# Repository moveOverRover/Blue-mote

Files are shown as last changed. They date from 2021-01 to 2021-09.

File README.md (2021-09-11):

# Blue-mote
This contains the stl files, code, and media for my Bluetooth remote project. But has more recently been taken over by my adventures of creating an android application to replace the remote (please do have a look at that, its pretty cool).
  
I started this project well over a year ago and it taught me a lot, certainly more than I want to write in this read me. Visiting the code of each project version will provide a deeper dive into the challenges and victories I found.

A lot of this repo is my first creating a controller, and then spending a year trying to figure out why half the time the messages I receive are not the ones I sent even though Bluetooth has a pretty bullet proof protocol.

I dig into parity, checksums, message frames, and end up making something like my own protocol even though I have never run it on hardware that isn’t already running its own error correction (although I might buy some cheep transmitters/receivers that have nothing else going on and give it a shot later).

In the end I believe the problem was my placing long wires in noisy environments between the simpler UART interfaces that was giving me the problem (1 parity bit might not be enough with a 2kw motor next to it). It was either that or a misunderstanding of how Arduino’s/HC-05 input buffers work because sometimes they would give me unreasonable values.
<p float="left">
  Screenshot_20210810-084741_BluetoothShenanegans2
  Screenshot_20210810-084846_BluetoothShenanegans3
</p>

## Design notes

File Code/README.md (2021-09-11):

# All arduino code lives here
Note: As of 2021-09-09 all of this code is legacy

remoteRover and miniJeep are two robots I built for testing the controller on. I wanted to upgrade the smaller remoteRover but I never got to it and its sitting disassembled for the time being. A lot more testing was done on miniJeep so the code there is more interesting. remoteControl is obviously just the physical remote.

A note about minijeep, it was a power wheels car, the kind of electric car parents buy for their kids. Someone was throwing it out if you can believe it, all it needed was a new battery. After that I made it remote control but that’s a story for another read me.

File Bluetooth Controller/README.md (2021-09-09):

# Stl files for 3d printing the controller

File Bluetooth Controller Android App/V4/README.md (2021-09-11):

# This version Is a game changer!

All the problems I have been having with unreliable communications have been solved with the version.
The way I did this is by implementing my most complicated message frame yet, I call it Butter-Scotch.
And this is what it looks like:

Butter Scotch message frame:

 each capital letter is a nibble, lowercase is a bit, * is multiplication
 
 by Bytes:                            AA AA Bxxxc DD 1-250*EE FF FF
 
                AA                AA     B             xxxc              DD           1-250* EE        FF FF
                
   message length^ | message length^ | ID^ | Received bit?^ | message type^ | message contents^ | check sum^
   
 Overview:
 
 I was inspired after learning about the CAN bus protocol and I implemented a few key parts of it. When the device receives data to its input buffer it will wait until
 at least 2 bytes have been received. then the message length can be decoded by reading the first 2 bytes as binary numbers and making sure they are the same (if they are different, we, have corruption and we can decide what to do with that). Now that we know the message length we can take in the right number of bytes and check that the data is good using the
 checksum at the end of the data. The ID is useful if multiple devices are hooked up to a single Bluetooth module on the Arduino side, this allows the Arduino to determine if the
 message is intended for it. The ID byte also contains a 3 don’t care bits and a acknowledge bit that so the device can determine if the previous message was received and decide what to do.
 The message type byte is a binary number that is a code in a shared array or HashMap that contains the instructions on what to do with the message content bytes.
 finally the checksum ensures good data.
 
 Message contents:
 
 The message contents are a series of binary numbers that can be interpreted in different ways based on the message type's value.
 For example: if the message type is 1 then interpret the binary contents as 3 integers 1 byte long each. If you can map whatever data you want to send to a single byte then
 the frame becomes very convenient. I have functions and classes that do this but what if you want to send something more complicated than a short short int? Well, I have functions
 and classes for that too. A float for example would be sent with a different message type to indicate how it should be read. Floats are not stored in the message traditionally
 with a sign bit, an exponent and a fraction. Instead, I chose to separate the float into 2 parts: the first is a variable length integer that represents the numbers before the decimal
 and a 2-byte integer representing the numbers after the decimal. Once received I just splice them back together. I choose to do it this way because it was easier for me since I already had
 all the functions to do this. The pit falls of doing it this way are you would need a whole byte to show its a negative number (but I’ve never need to send a negative float yet) and its not
 space efficient (which I don’t care about since the message can be 250 bytes long). finally, strings are just sent as ascii with an appropriate type. There are better ways to do this
 but this is my way, and it works!
 
 App updates:
 
 This version actually receives data from the Arduino and can display it with its new custom progress bar. 1 for motor temperature, 1 for battery voltage, and 1 for throttle input (on the smartphone side). Along with that the text view now display stats about the messaging between the Arduino and the phone for debugging and connection health. I also have added a new menu to change the leds that are now on my electric long board. You can set them to be any color with sliders, and also choose from a mix of colors or action mode which is green when accelerating, blue when costing and red when braking. But most impressively this communication finally has no errors. I can detect errors on both the Arduino side and the app side because of the received bit and checksum in the message frame. However, since I can now confidently read the length of the message without using the input buffers 'Available()' function I have not had a single error. It is finally working how it should have from the first place. I don’t know why the input buffer on both the app side and the Arduino side is falsely reporting the size of the received data but not paying any attention seems to have fixed that problem. All this time and I still don’t know why, but now I know how and that feels great.

 <p float="left">
  Screenshot_20210810-084741_BluetoothShenanegans2
  Screenshot_20210810-084846_BluetoothShenanegans3
  Screenshot_20210810-084846_BluetoothShenanegans3
</p>

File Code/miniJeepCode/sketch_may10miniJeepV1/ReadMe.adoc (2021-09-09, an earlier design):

:Author: moveoverrover
:Email: {AuthorEmail}
:Date: 10/05/2021
:Revision: version#
:License: Public Domain

= Project: {Project}

Describe your project

== Step 1: Installation
Please describe the steps to install this project.

For example:

1. Open this file
2. Edit as you like
3. Release to the World!

== Step 2: Assemble the circuit

Assemble the circuit following the diagram layout.png attached to the sketch

== Step 3: Load the code

Upload the code contained in this sketch on to your board

=== Folder structure

....
 sketch123                => Arduino sketch folder
  ├── sketch123.ino       => main Arduino file
  ├── schematics.png      => (optional) an image of the required schematics
  ├── layout.png          => (optional) an image of the layout
  └── ReadMe.adoc         => this file
....

=== License
This project is released under a {License} License.

=== Contributing
To contribute to this project please contact moveoverrover https://id.arduino.cc/moveoverrover

=== BOM
Add the bill of the materials you need for this project.

|===
| ID | Part name      | Part number | Quantity
| R1 | 10k Resistor   | 1234-abcd   | 10
| L1 | Red LED        | 2345-asdf   | 5
| A1 | Arduino Zero   | ABX00066    | 1
|===

=== Help
This document is written in the _AsciiDoc_ format, a markup language to describe documents.
If you need help you can search the http://www.methods.co.nz/asciidoc[AsciiDoc homepage]
or consult the http://powerman.name/doc/asciidoc[AsciiDoc cheatsheet]

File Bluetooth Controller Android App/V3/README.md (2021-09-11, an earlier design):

# V3

This version adds 2 analog inputs because of the digital joystick.

This implementation of the joystick was not perfect.
I had trouble offsetting the sprite of the joystick from the position of the finger because the coordinates of the sprite start at the top left corner of the sprite not the middle.
Some strange looking offsets had to made because of this and it interfered with the way I would map the position of the joystick to its actual value.

Other than that, pretty similar to V2.
I did clean up the UI and switched it to a relative layout. I Also implement some new features like toasts and an option to set the origin of the joystick anywhere on the screen.
Because of these changes this version of the app should* fit on any phone screen unlike the last one.
We are still using the miniJeep3 message frame as well.

<p float="left">
  Screenshot_20210810-084741_BluetoothShenanegans2
  Screenshot_20210810-084846_BluetoothShenanegans3
</p>

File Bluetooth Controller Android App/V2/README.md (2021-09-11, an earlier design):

# V2
Very first working version of the Bluetooth app. Used digital button inputs to emulate the message frame that miniJeep3 was receiving (check out moveOverRover/Blue-mote/code for more details).UI was not great, and everything was on a relative layout But it did work however and it taught me a lot. The next version improved on a lot of the short comings of this such as analog inputs and better UI.
<p float="left">
  Screenshot_20210810-084741_BluetoothShenanegans2
  Screenshot_20210810-084846_BluetoothShenanegans3
</p>

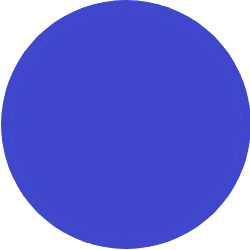
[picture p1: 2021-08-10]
Bluetooth Controller Android App/V4/pad.png

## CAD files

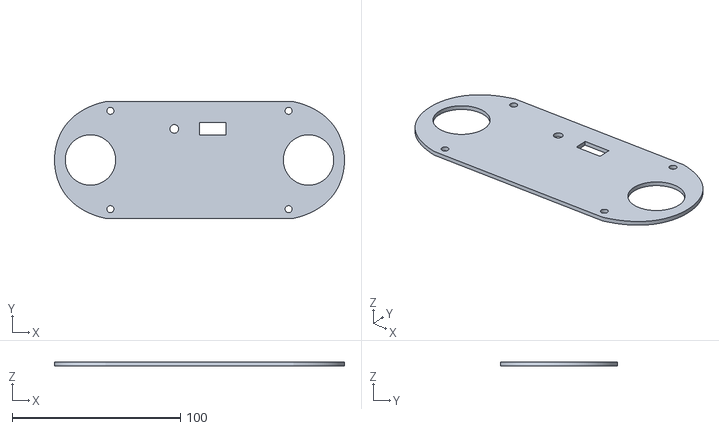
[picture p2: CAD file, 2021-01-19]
Bluetooth Controller/Blue-mote cover v3.stl
172.5 x 69.5 x 2.25

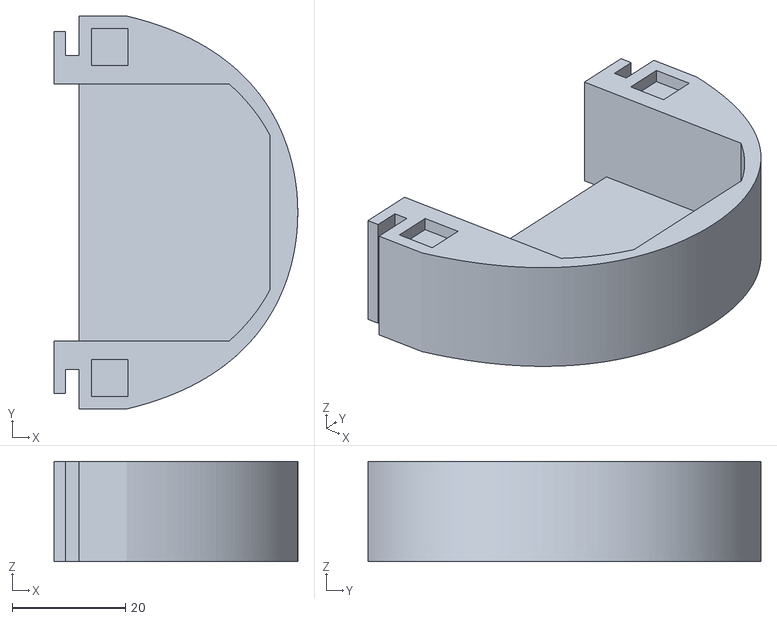
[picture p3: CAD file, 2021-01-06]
Bluetooth Controller/New Joystick compartment A v1.stl
43.1 x 69.5 x 17.8

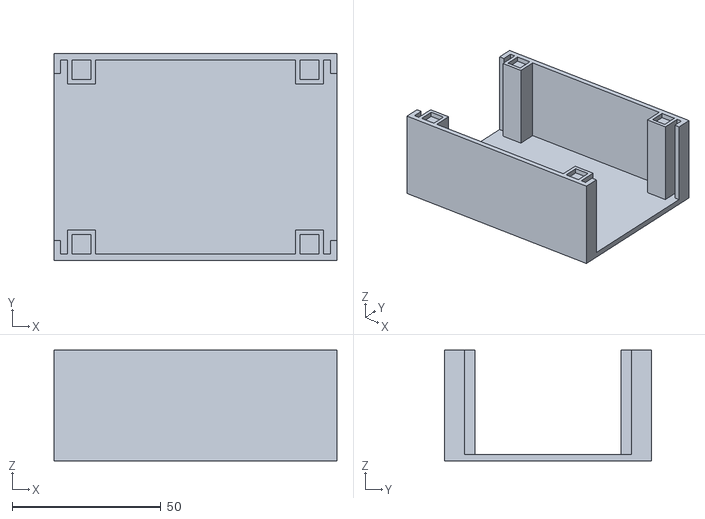
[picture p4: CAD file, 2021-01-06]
Bluetooth Controller/Bluetooth Remote Core A v4.stl
95.0 x 69.5 x 37.2

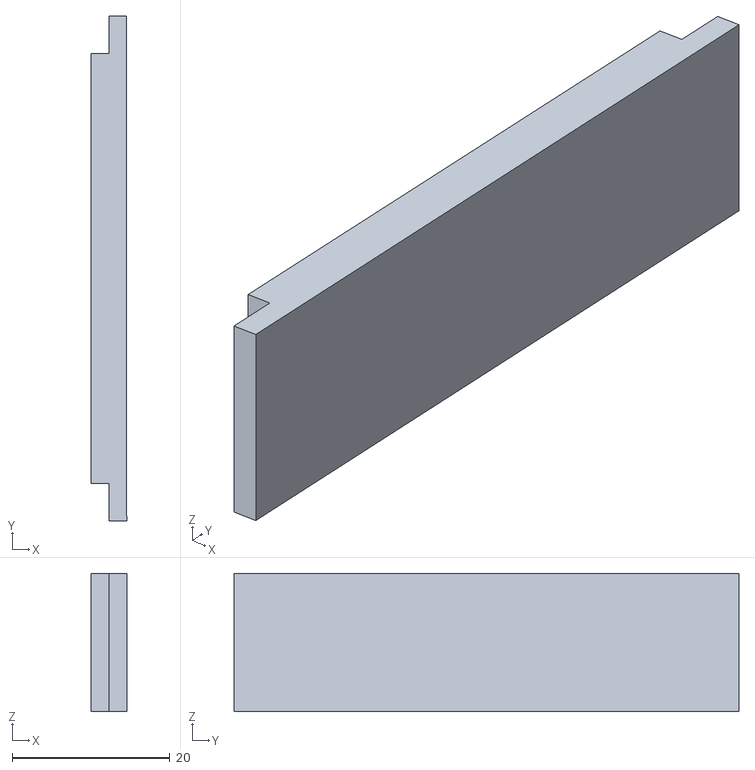
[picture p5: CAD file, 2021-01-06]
Bluetooth Controller/Bluetooth cover small v1.stl
4.50 x 64.0 x 17.5

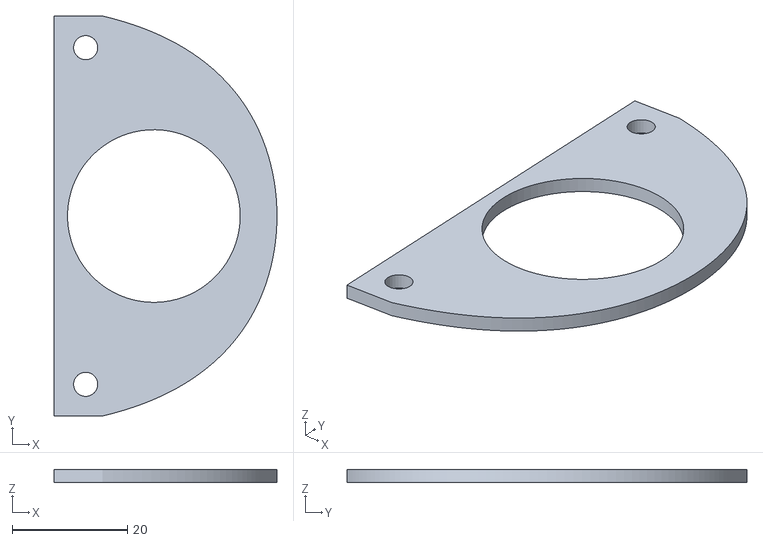
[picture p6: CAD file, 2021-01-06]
Bluetooth Controller/Joystick cover v2.stl
38.7 x 69.5 x 2.25

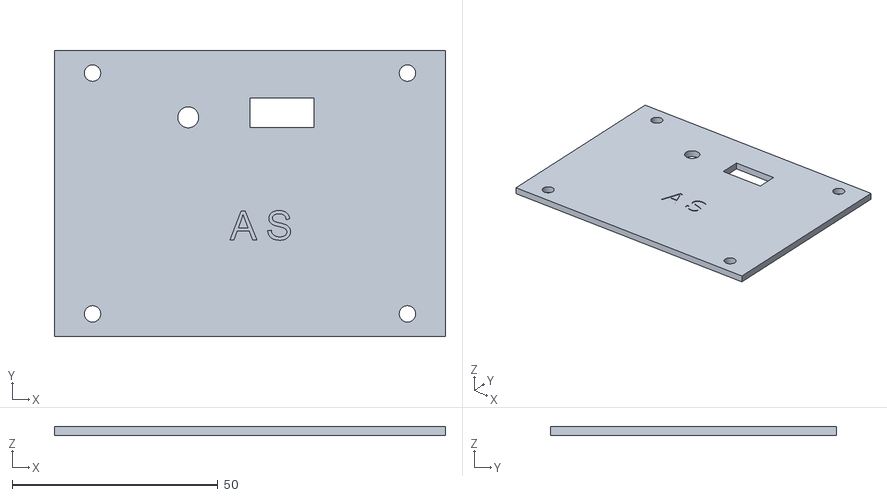
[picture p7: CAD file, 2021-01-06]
Bluetooth Controller/B Bluetooth Core v3.stl
95.0 x 69.5 x 2.25

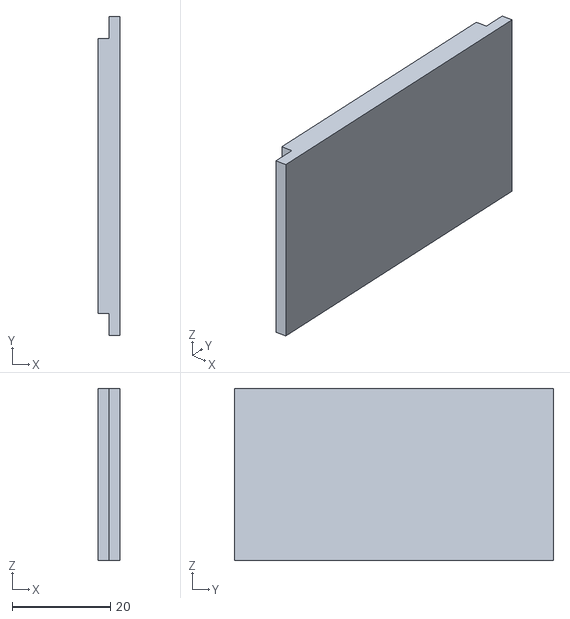
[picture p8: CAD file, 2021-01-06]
Bluetooth Controller/cover Bluetooth v2.stl
4.45 x 65.0 x 35.0

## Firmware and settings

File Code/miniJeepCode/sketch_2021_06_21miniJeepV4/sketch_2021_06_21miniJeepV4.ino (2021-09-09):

/* author: Alex Semenov
  Forth resonable working version
  Very simmialr to the third version but now we attempt to talk back to the controller with some data. Never was used after I made this I quickly tranitioned
  to using Butter Scotch after this was complete.
*/
#define INC_MSG 7 // size of the incomming message
#define OUT_MSG 5 // size of the outgoing message

#define D1 3 // drive pin one
#define D2 4 // drive pin two
#define D3 5 // drive pin three
#define T1 6 // turning pin one
#define T2 7 // turning pin two
#define T3 8 // turning pin three
#define HORN 11 
#define LIGHTS 10
#define MUSIC 12
#define X_UPPER 175 // upper limit of dead zone x joystick 
#define X_LOWER 80 // lower limit of dead zone x joystick
#define Y_UPPER 175 // upper limit of dead zone y joystick 
#define Y_LOWER 75 // lower limit of dead zone y joystick
#define SAFTY_PIN 2 // pint that reads the state of the bluetooth modual

int x = 130; // current x position
int y = 130; // current y position
int z = 0; // state of digital functions
char horn = 'b'; 
char lights = 'd';
char music = 'f';
volatile int p = 0; // if information has been resently recived p=0
char cmd[INC_MSG]; // incoming message
char srt; // buffer var
char ret[OUT_MSG];
volatile int j; // amount of serial events

int power(int a, int b){ // a = base, b = exponent
  if(b==0){
    return 1;
  }
  int og = a;
  for(int q=0; q<b-1; q++){
    a = a*og;
  }
  return a;
}

unsigned long int bytes2Int(char *bytes, int leng, int offset){ // makes a series of bytes into a binary number which is returned as an integer
 byte mask;
 unsigned long int sum = 0;
  
  for (int i=leng; i>offset; i--){ // repetes untill every byte has been prosessed start at last byte
    mask = 0x01;
    for (int k=0; k<8; k++){ // start at first bit
      if(bytes[i-1] & mask){ // if bit is 1
       sum += power(2,k+(8*(leng-i))); // add bit
      }
      mask <<= 1; // bit shift mask to the left
    }
  }
  return sum;
}

void int2Bytes(int num, char* bytes, int leng, int offset){ // writes a binary number from an int
  for (int i=offset; i<leng+offset; i++){ //sets all bits in message to 0
    bytes[i] = 0x00;
  }
  
  if (num%2 != 0){ // if num is odd then we know the first bit is a 1
    bytes[leng+offset-1] = bytes[leng+offset-1] | 0x01;
  }
  
  int shift, pos;
  byte mask;
  int tempNum = num;
  
  while ((shift=int2Bit(tempNum)) != 0){ // while there is bits left to add
    tempNum = tempNum - power(2,shift); // removes previous bit
    mask = 0x01; // resets the mask
    mask <<= shift%8; // moves the mask to the current bit
    pos = bytePos(leng, shift); //finds the current byte
    bytes[pos+offset] = bytes[pos+offset] | mask; // adds the bit to the byte
  }
}

int int2Bit(int tempNum){ // determines bigest bit position of checksum
  int k =0;
  while((tempNum =tempNum/2) >= 1){
   k++; 
  }
  return k;
}

int bytePos(int leng, int shift){ // counts the byte we are on based on the shift
  int pos = 0;
  while (shift>7){
    shift -=8;
    pos++;
  }
  return leng-pos-1; // -1 because arrays start at 0
}

int cSum(char* bytes, int leng){ // calcualtes integer checksum
  int sum =0;
  for (int k=0; k<leng; k++){
    sum+=bytes2Int(&bytes[k],1,0);
  }
  return sum;
}

void actions () {
  // this is for steering
  if (x > X_UPPER){
    digitalWrite(T1,HIGH);
    digitalWrite(T2,LOW);
    digitalWrite(T3,HIGH); 
  } else if (x < X_LOWER){
    digitalWrite(T1,HIGH);
    digitalWrite(T2,HIGH);
    digitalWrite(T3,LOW);
  } else {
    digitalWrite(T1,LOW);
    digitalWrite(T2,LOW);
    digitalWrite(T3,LOW);
  }
  // this is for dirving
  if (y > Y_UPPER){
    digitalWrite(D3,HIGH);
    digitalWrite(D2,LOW);
    digitalWrite(D1,HIGH);
  } else if (y < Y_LOWER) {
    digitalWrite(D3,HIGH);
    digitalWrite(D2,HIGH);
    digitalWrite(D1,LOW);
  } else {
    digitalWrite(D3,LOW);
    digitalWrite(D2,LOW);
    digitalWrite(D1,LOW);
  }
  
  // this is for the features
  if (horn == 'a') {
    digitalWrite(HORN, HIGH);
  } else if (horn == 'b') {
    digitalWrite(HORN, LOW);
  }
  if (lights == 'c') {
    digitalWrite(LIGHTS, HIGH);
  } else if (lights == 'd'){
    digitalWrite(LIGHTS, LOW);
  }
  if (music == 'e') {
    digitalWrite(MUSIC, HIGH);
  } else if (music == 'f') {
    digitalWrite(MUSIC, LOW);
  }
}

void serialEvent(){
  p=0; // good connection
  j++; // counts a serial event
  TCNT1  = 0x00; // should reset timer
}

void zDoer(){
  if(z == 0){ // OFF
    horn = 'b';
    lights = 'd';
    music = 'f';
  } else if (z == 1){ // LIGHTS
    horn = 'b';
    lights = 'c';
    music = 'f';
  } else if (z == 2){ // LIGHTS and HORN
    horn = 'a';
    lights = 'c';
    music = 'f';
  } else if (z == 3){ //  LIGHTS and MUSIC
    horn = 'b';
    lights = 'c';
    music = 'e';
  } else if (z == 4){ // HORN
    horn = 'a';
    lights = 'd';
    music = 'f';
  } else if (z == 5){ // MUSIC
    horn = 'b';
    lights = 'd';
    music = 'e';
  }
}

char* takeIn(char *bytes){
  int i=0;
  int flag = 0;
  while((srt = Serial.read()) != -1){ // read entire message to memory
    delay(2); // could by shorter?
    if(i<INC_MSG){
      bytes[i++] = srt;
    }
  }
  if (i==INC_MSG){ // if too few or too many bytes are recived throw the message away
    return bytes;
  } else {
    return NULL;
  }
}

ISR(TIMER1_COMPA_vect){//timer1 interrupt 5Hz: if timer is ever aloud to complete we have a bad connection
  p = 1; // bad connection
}

void debuggin(){
  /*
  Serial.print("cmd: ");
    for(int i=0;i<INC_MSG;i++){
      Serial.write(cmd[i]);
    }
    Serial.write('\n');
  
    Serial.print("a_x: ");
    Serial.println(bytes2Int(&cmd[0],1));
    Serial.print("a_y: ");
    Serial.println(bytes2Int(&cmd[1],1));
    Serial.print("b_x: ");
    Serial.println(bytes2Int(&cmd[2],1));
    Serial.print("b_y: ");
    Serial.println(bytes2Int(&cmd[3],1));
    Serial.print("z: ");
    Serial.println(z);
    
    Serial.print(cSum(cmd,5));
    Serial.print(" = ");
    Serial.println(bytes2Int(cmd,7,5));
    */

    Serial.print("0: ");
    Serial.println(x);
    Serial.print("1: ");
    Serial.println(bytes2Int(&cmd[1],1,0));
    Serial.print("2: ");
    Serial.println(bytes2Int(&cmd[2],1,0));
    Serial.print("3: ");
    Serial.println(y);
    
}

void setup(){ // compare match register = [16,000,000Hz/(prescaler*desired interupt frequency)]-1
  for(int k=3; k<13; k++){ // set all pins but 2 to be output
    if (k!=6){ // pin 6 has an internal short on current board
       pinMode(k,OUTPUT);
    }
    //digitalWrite(k, LOW);
  }
  Serial.begin(38400);
  pinMode(SAFTY_PIN, INPUT);
  pinMode(13,OUTPUT);
  j=0; // Very important to make zero

  cli(); //stop interrupts
  //set timer1 to 10Hz
  TCCR1A = 0;// set entire TCCR1A register to 0
  TCCR1B = 0;// same for TCCR1B
  TCNT1  = 0;//initialize counter value to 0
  // set compare match register for 10hz increments
  //OCR1A = 1500;// = (16*10^6) / (10*1024) - 1 (must be <65536) ***VERY IMPORTANT*** -LIKES TO BE A NUMBER THAT ENDS IN AT LEAST ONE '0', I HAVE NO IDEA WHY JUST LEAVE IT BE!
  OCR1A = 3000; // double the pervious time becuase it runs better this way
  // turn on CTC mode
  TCCR1B |= (1 << WGM12);
  // Set CS12 and CS10 bits for 1024 prescaler
  TCCR1B |= (1 << CS12) | (1 << CS10);  
  // enable timer compare interrupt
  TIMSK1 |= (1 << OCIE1A);
  sei();//allow interrupts
}

void loop() {
  if(j>INC_MSG){ //once enough bytes have been recived
    j=0;  // reset the war clock
    if (takeIn(cmd) != NULL){ // take in the bytes
      if (cSum(cmd,5) == bytes2Int(cmd,7,5)){ // if the check sum checks out then we can change stuff
        x = bytes2Int(&cmd[0],1,0);
        y = bytes2Int(&cmd[3],1,0);
        z = bytes2Int(&cmd[4],1,0);

        int2Bytes(1,ret,1,0); // if data was good then send good data conformation
      } else {
        int2Bytes(0,ret,1,0); // if data was bad then send bad data conformation
      }
      debuggin();
    } else {
      int2Bytes(0,ret,1,0); // if data was bad then send bad data conformation
    }
    int2Bytes(2,ret,1,1); // message contents
    int2Bytes(3,ret,1,2); // message contents
    int2Bytes(cSum(ret,3), ret, 2, 3); // checksum
    //for(int i=0; i<OUT_MSG; i++){
      //Serial.write(ret[i]);
    //}
  }
  
 if (p == 0 && digitalRead(SAFTY_PIN) == LOW){ // good conection *** saftey pin set low for testing
   digitalWrite(13,HIGH);
   zDoer();
   actions();
 } else { // bad conection
   digitalWrite(13,LOW);
   x = 130;
   y = 130;
   horn = 'b';
   lights = 'd';
   music = 'f';
   actions();
 }
}

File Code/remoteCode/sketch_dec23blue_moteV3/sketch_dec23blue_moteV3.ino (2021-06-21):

/* author: Alex Semenov
  Third resonable working version of the blue-tooth remote.
  Sends 2 more analog inputs than hte previous version (It now is sending every imput it has)
  Sends data at a lower resolution 8bit instead of 10 but with much more freqent sends and more data per send
  Calculates a checksum and send it with the data for error checking
  Much faster than the previous version (remeber to reduce the delay later can prolly be about 40)
*/
#define X_A A3 //left Joystick x-axis
#define Y_A A1 //left Joystick y-axis
#define X_B A4 //right Joysitck x-axis
#define Y_B A2 //right Joystick y-axis
#define TOGGLE 2
#define BTN_A 3
#define BTN_B 4
#define R 5 
#define B 6
#define G 7
int x_a, y_a, x_b, y_b, toggle, btn_a, btn_b, z;
char cmd [7];
char btn_c[4];

int power(int a, int b){ // a = base, b = exponent
  if(b==0){
    return 1;
  }
  int og = a;
  for(int q=0; q<b-1; q++){
    a = a*og;
  }
  return a;
}

byte int2Byte(int x, boolean yesMap){ // helper function
  if (yesMap){
    x = map(x, 0, 1023, 0, 255); //must fit in one byte
  }
  return (byte)x;
}

void byteSum(int checkSum, char* msg){ // writes a 2 bit binary number to be used as the checksum
  msg[5] = 0x00;
  msg[6] = 0x00;
  
  if (checkSum < 256){ // if the check sum is small we only need one byte so we can write the other one to be 0
    msg[5] = 0x00;
    msg[6] = (char)int2Byte(checkSum,false);
    return;
  }
  
  if (checkSum%2 != 0){ // if checkSum is odd then we know the first bit is a 1
    cmd[6] = cmd[6] | 0x01;
  }
  
  int shift;
  byte mask;
  int tempSum = checkSum;
  
  while ((shift=int2Bit(tempSum)) != 0){ // I forgot how all of this works too
    //Serial.print(shift);
    //Serial.print(": ");
    //Serial.println(tempSum);
    tempSum = tempSum - power(2,shift);
    mask = 0x01;
    if (shift > 7){
      shift -=8;
      mask <<= shift;
      msg[5] = msg[5] | mask;
    } else {
      mask <<= shift;
      msg[6] = msg[6] | mask;
    }
  }
}

int int2Bit(int tempSum){ // determines bigest bit position of checksum *** helper function
  int k =0;
  while((tempSum =tempSum/2) >= 1){
   k++; 
  }
  return k;
}

unsigned long int getSum(char *msg, int leng){ // makes a serires of bytes into a binary number which is returned as an integer
 byte mask;
 unsigned long int sum = 0;
  
  for (int i=leng; i>0; i--){ // repetes untill every byte has been prosessed start at last byte
    //if (msg[i-1] == 0x00){
    //  return 0;
    //}
    mask = 0x01;
    for (int j=0; j<8; j++){ // start at first bit
      if(msg[i-1] & mask){ // if bit is 1
       sum += power(2,j+(8*(leng-i))); // add bit
      }
      mask <<= 1; // bit shift mask to the left
    }
  }
  return sum;
}

int cSum(char* msg, int leng){ // calcualtes integer checksum
  int sum =0;
  for (int k=0; k<leng; k++){
    sum+=getSum(&msg[k],1);
  }
  return sum;
}

void assemble(char* msg){ // makes the message
  int checkSum = 0;
  msg[0] = (char)int2Byte(x_a, true);
  msg[1] = (char)int2Byte(x_b, true);
  msg[2] = (char)int2Byte(y_a, true);
  msg[3] = (char)int2Byte(y_b, true);
  msg[4] = (char)int2Byte(z, false);
  byteSum(cSum(cmd, 5), cmd);
}

void zDoer(){ // inner btn has proprity over outer btn
  if (btn_c[0] == 'b' && btn_c[1] == 'd' && btn_c[3] == 'f'){ // nothing
    z=0;
  } else if (btn_c[0] == 'a' && btn_c[1] == 'd' && btn_c[2] == 'f'){ // toggle
    z=1;
  } else if (btn_c[0] == 'a' && btn_c[1] == 'c' && btn_c[2] == 'f'){ // toggle + inner
    z=2;
  } else if (btn_c[0] == 'a' && btn_c[1] == 'd' && btn_c[2] == 'e') { // toggel + outer
    z=3;
  } else if (btn_c[1] == 'c') { // inner
    z=4;
  } else if (btn_c[2] == 'e') { // outer
    z=5;
  }
}

void btns(){
  if (toggle == 1) {
    digitalWrite(R, HIGH);
    digitalWrite(B, LOW);
    digitalWrite(G, LOW);
    btn_c[0] = 'a';
  } else {
    btn_c[0] = 'b';
  }
  if (btn_a == 1) {
    digitalWrite(R, LOW);
    digitalWrite(B, HIGH);
    digitalWrite(G, LOW);
    btn_c[1] = 'c';
  }else {
    btn_c[1] ='d';
  }
  if (btn_b == 1) {
    digitalWrite(R, LOW);
    digitalWrite(B, LOW);
    digitalWrite(G, HIGH);
    btn_c[2] = 'e';
  }else {
    btn_c[2] = 'f';
  }
  if (toggle != 1 && btn_a != 1 && btn_b != 1){
    digitalWrite(R, LOW);
    digitalWrite(B, LOW);
    digitalWrite(G, LOW);
  }
}

void printMsg(){
 for(int i=0; i<7; i++){
  Serial.write(cmd[i]);
 }
}

void setup() {
  Serial.begin(38400);
  pinMode(TOGGLE, INPUT);
  pinMode(BTN_A, INPUT);
  pinMode(BTN_B, INPUT);
  pinMode(R, OUTPUT);
  pinMode(G, OUTPUT);
  pinMode(B, OUTPUT);
}

void loop() {
  delay(40); // the reciver needs this big of a delay becuase of the speed it reads data in
  // read all sensor data
  x_a = analogRead(X_A);
  y_a = analogRead(Y_A);
  x_b = analogRead(X_B);
  y_b = analogRead(Y_B);
  toggle = digitalRead(TOGGLE);
  btn_a = digitalRead(BTN_A);
  btn_b = digitalRead(BTN_B);
  
  btns(); // lights up the led and configs the button data
  zDoer(); // finds the z byte ascii value
  assemble(cmd);
  
  if(toggle == HIGH){ // if the toggle is high then enable transmission otherwise do nothing
    printMsg();
  }
}
